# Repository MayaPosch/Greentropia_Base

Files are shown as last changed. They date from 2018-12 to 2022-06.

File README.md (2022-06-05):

# Greentropia Base Board #

The [Greentropia](http://www.nyantronics.com/greentropia.php "Greentropia") (formerly IoP) Base board is a fairly simple PCB aimed at monitoring and watering single plants or similar configurations. Its block diagram looks as follows:

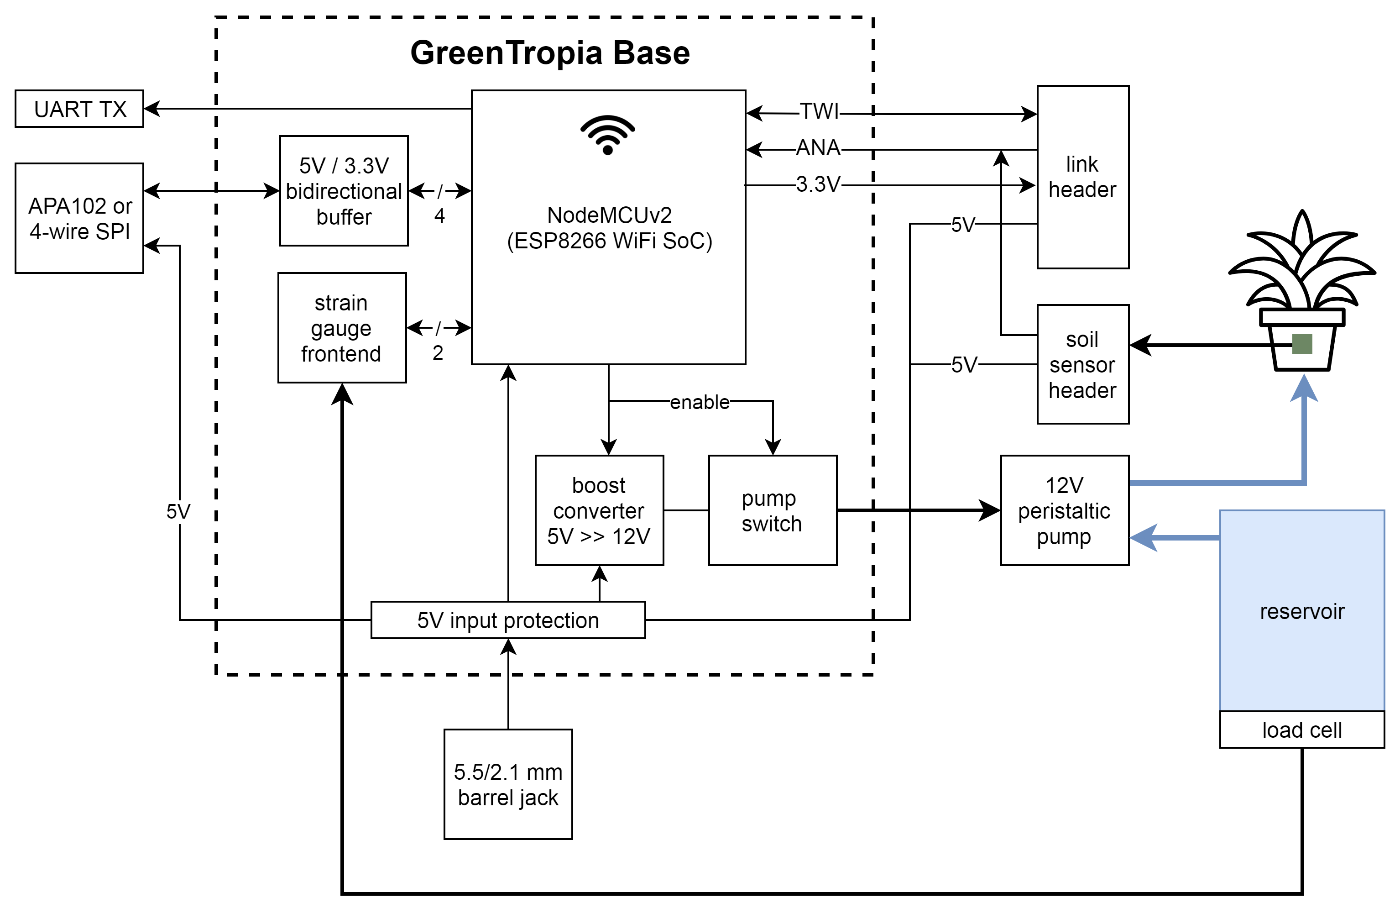
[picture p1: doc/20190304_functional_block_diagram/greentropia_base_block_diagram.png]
Base Diagram


This is the final board (without NodeMCU board installed):

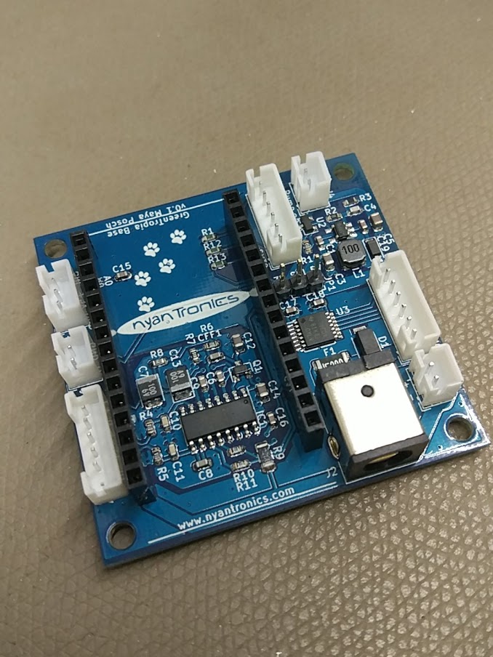
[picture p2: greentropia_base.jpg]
Base Board


This repository contains the full KiCad project for the board. More information about the Greentropia project can be found at [Nyantronics](http://nyantronics.com/ "Nyantronics.com").

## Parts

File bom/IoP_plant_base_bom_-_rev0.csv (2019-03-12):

Id | Designator | Package | Quantity | Designation | Supplier and ref
1 | U1 | DIP2286W64P254L4826H735Q30N | 1 | NodeMCUv2
2 | SPI0,EXT0 | JST_PH_B6B-PH-K_1x06_P2.00mm_Vertical | 2 | Conn_01x06
3 | J4,J1,J6 | JST_PH_B2B-PH-K_1x02_P2.00mm_Vertical | 3 | Conn_01x02
4 | U2 | SOT-23-5_HandSoldering | 1 | LM27313XMF
5 | U3 | TSSOP-14_4.4x5mm_P0.65mm | 1 | TXB0104PWR
6 | R14,R5,R4,R10,R11 | R_0603_1608Metric | 5 | 100
7 | R13,R12,R1 | R_0603_1608Metric | 3 | 4.7k
8 | Q2 | SOT-23 | 1 | IRLML6244
9 | JP1 | PinHeader_1x03_P2.54mm_Vertical | 1 | Jumper_3_Bridged12
10 | D3 | D_SOD-523 | 1 | ESD5Z12T1G
11 | C19,C18,C17,C1,C16,C6 | C_0603_1608Metric | 6 | 100nF
12 | C5 | C_0805_2012Metric | 1 | 4.7uF
14 | J2 | BarrelJack_CUI_PJ-063AH_Horizontal | 1 | Jack-DC
15 | J5 | JST_PH_B3B-PH-K_1x03_P2.00mm_Vertical | 1 | Conn_01x03
16 | J7 | JST_PH_B5B-PH-K_1x05_P2.00mm_Vertical | 1 | Conn_01x05
17 | D1 | D_SMA | 1 | 1N4004
18 | F1 | Fuse_1812_4532Metric | 1 | Polyfuse
19 | R9 | R_1206_3216Metric | 1 | 100R
20 | C3,C12,C14 | C_0805_2012Metric | 3 | 10uF
21 | C15,C9 | C_0603_1608Metric | 2 | 0.1uF
22 | C4 | C_0603_1608Metric | 1 | 220pF
23 | C8,CFF1 | C_0603_1608Metric | 2 | 1uF
24 | D2 | D_SOD-123 | 1 | MBR0520L
25 | R7 | R_0603_1608Metric | 1 | 1.0k
26 | R6 | R_0603_1608Metric | 1 | 2.0k
27 | R3 | R_0603_1608Metric | 1 | 117K
28 | R2 | R_0603_1608Metric | 1 | 13.3K
29 | L1 | L_Wuerth_MAPI-4020 | 1 | 10uH
30 | IC1 | SOIC-16_3.9x9.9mm_Pitch1.27mm | 1 | HX711
31 | R8 | R_0603_1608Metric | 1 | 10R
32 | Q1 | SOT-23 | 1 | BC857C
33 | C13,C7 | CP_EIA-3528-15_AVX-H | 2 | 100uF/6.3V
34 | C11,C10 | C_0603_1608Metric | 2 | 10nF

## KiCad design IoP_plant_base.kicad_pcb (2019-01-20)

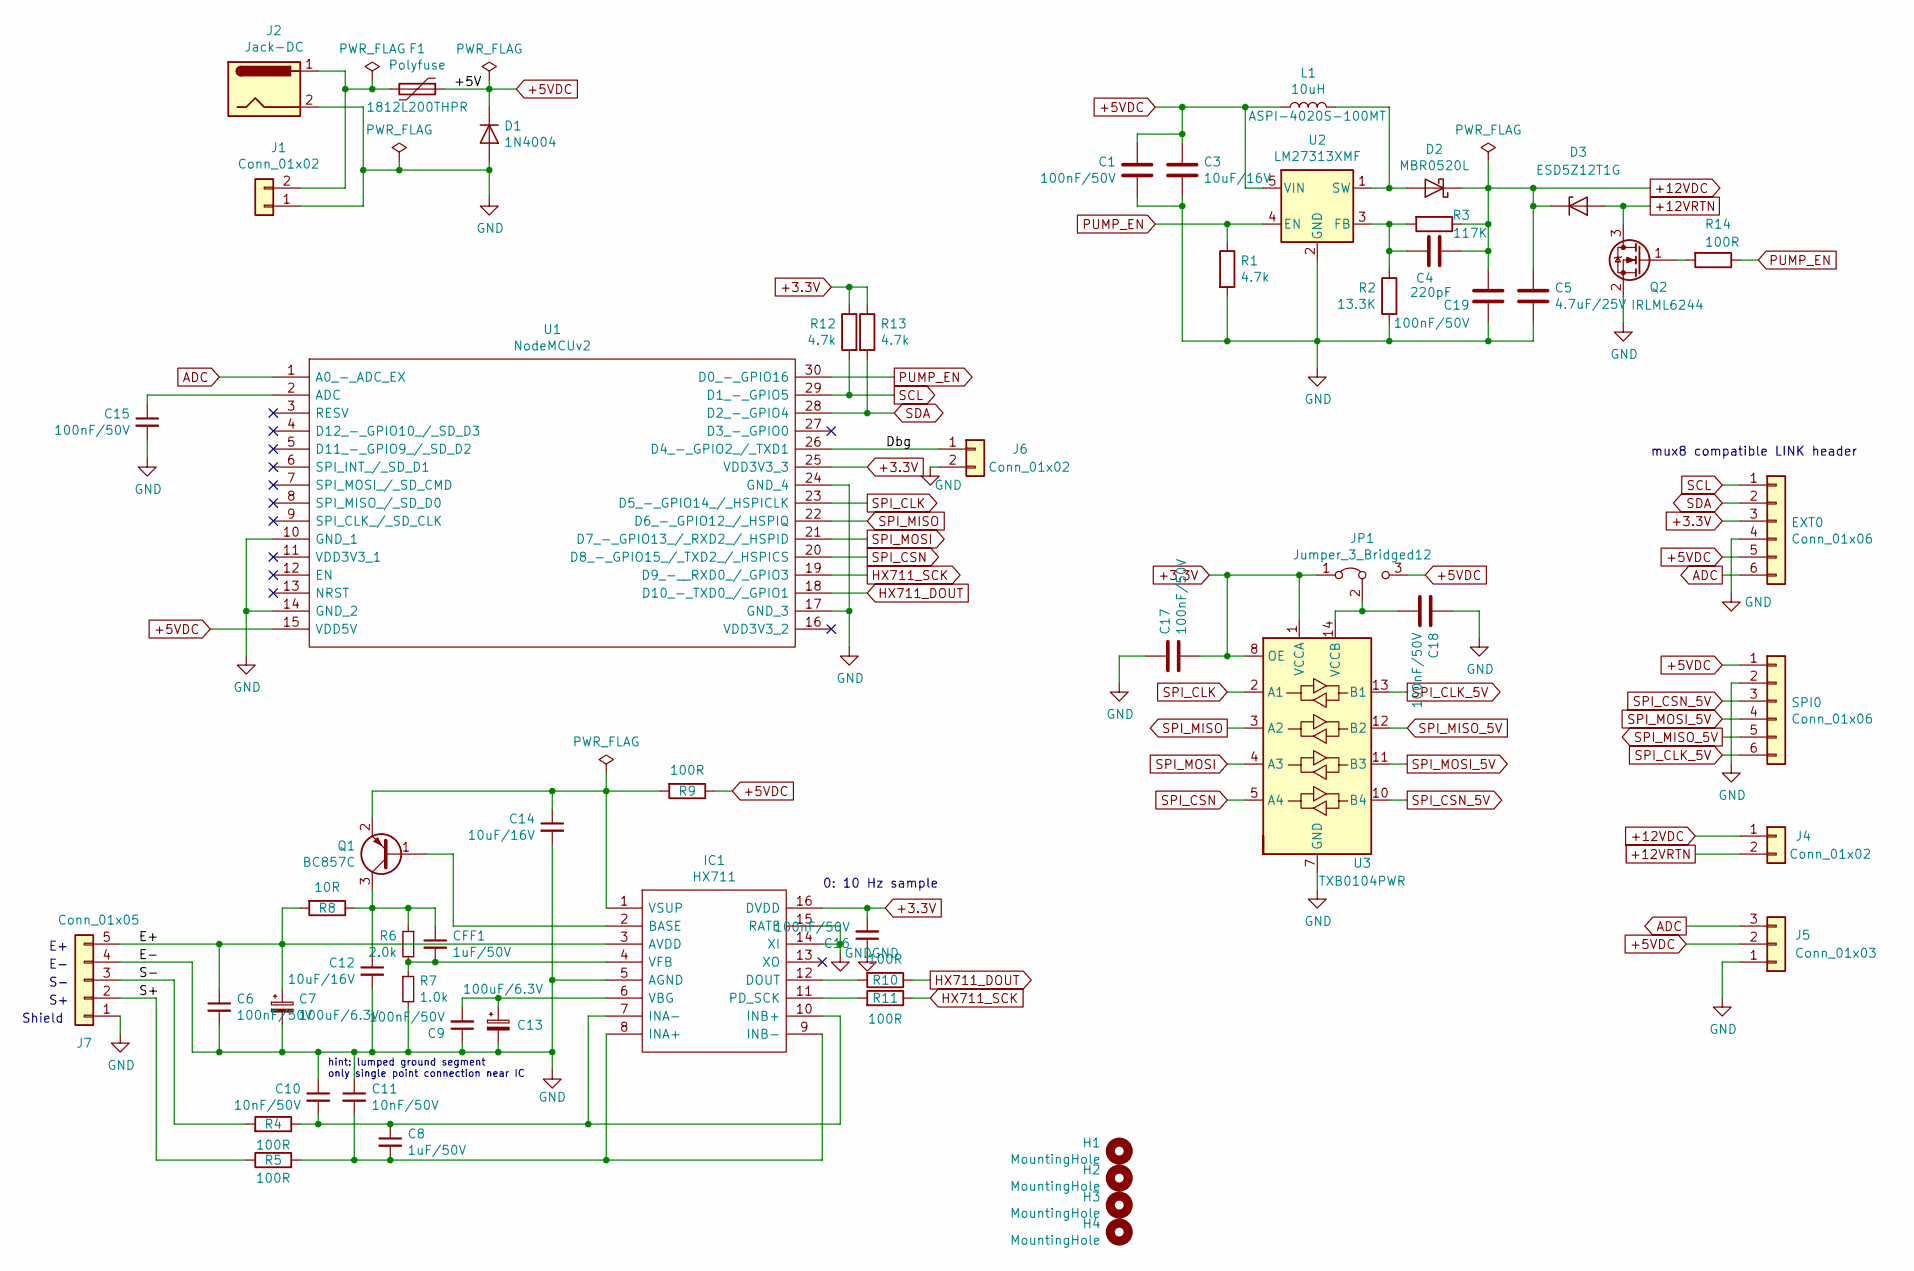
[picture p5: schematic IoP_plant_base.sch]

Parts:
C1, C6, C9, C15, C16, C17, C18, C19: 100nF/50V; C_0603_1608Metric; Mouser 603-CC603KRX7R9BB104
C3, C12, C14: 10uF/16V; C_0805_2012Metric; Mouser 80-C0805C475M9RAUTO
C4: 220pF; C_0603_1608Metric; Mouser 81-GCM1885C2A221J16D
C5: 4.7uF/25V; C_0805_2012Metric; Mouser 81-GCM21BC71E475KE6L
C7, C13: 100uF/6.3V; CP_EIA-3528-15_AVX-H; MPN F930J107KBA; Mouser 647-F930J107KBA
C8: 1uF/50V; C_0603_1608Metric; Mouser 963-LMK212B7225KG-T
C10, C11: 10nF/50V; C_0603_1608Metric; Mouser 710-885012206089
CFF1: 1uF/50V; C_0603_1608Metric; Mouser 963-LMK212B7225KG-T
D1: 1N4004; D_SMA; MPN MRA4004T3G; Mouser 863-MRA4004T3G
D2: MBR0520L; D_SOD-123; MPN MBR0520L; Mouser 512-MBR0520L
D3: ESD5Z12T1G; D_SOD-523; MPN ESD5Z12T1G; Mouser 863-ESD5Z12T1G
EXT0: Conn_01x06; JST_PH_B6B-PH-K_1x06_P2.00mm_Vertical; Digikey 455-1708-ND
F1: Polyfuse; Fuse_1812_4532Metric; MPN 1812L200THPR; Mouser 576-1812L200THPR
H1, H2, H3, H4: MountingHole; MountingHole_3.2mm_M3_DIN965
IC1: HX711; SOIC-16_3.9x9.9mm_Pitch1.27mm; Manufacturer_Part_Number HX711
J1, J4, J6: Conn_01x02; JST_PH_B2B-PH-K_1x02_P2.00mm_Vertical; Digikey 455-1704-ND
J2: Jack-DC; BarrelJack_CUI_PJ-063AH_Horizontal; MPN PJ-063AH; Mouser 490-PJ-063AH
J5: Conn_01x03; JST_PH_B3B-PH-K_1x03_P2.00mm_Vertical; Digikey 455-1705-ND
J7: Conn_01x05; JST_PH_B5B-PH-K_1x05_P2.00mm_Vertical; Digikey 455-1707-ND
JP1: Jumper_3_Bridged12; PinHeader_1x03_P2.54mm_Vertical
L1: 10uH; L_Wuerth_MAPI-4020; MPN2 74438357100; Mouser2 710-74438357100
Q1: BC857C; SOT-23; MPN BC857CWT1G; Mouser 863-BC857CWT1G
Q2: IRLML6244; SOT-23; MPN IRLML6244TRPBF; Mouser 942-IRLML6244TRPBF
R1, R12, R13: 4.7k; R_0603_1608Metric
R2: 13.3K; R_0603_1608Metric; Mouser 71-CRCW0603-13.3K-E3
R3: 117K; R_0603_1608Metric; Mouser 603-RT0603DRE07117KL
R4, R5, R10, R11, R14: 100R; R_0603_1608Metric
R6: 2.0k; R_0603_1608Metric; Mouser 71-CRCW0603-2.0K-E3
R7: 1.0k; R_0603_1608Metric
R8: 10R; R_0603_1608Metric
R9: 100R; R_1206_3216Metric
SPI0: Conn_01x06; JST_PH_B6B-PH-K_1x06_P2.00mm_Vertical; Digikey 455-1708-ND
U1: NodeMCUv2; DIP2286W64P254L4826H735Q30N; Mouser Part Number 713-113990105
U2: LM27313XMF; SOT-23-5_HandSoldering; MPN LM27313XMF/NOPB; Mouser 926-LM27313XMF/NOPB
U3: TXB0104PWR; TSSOP-14_4.4x5mm_P0.65mm; MPN TXB0104PWR; Mouser 595-TXB0104PWR

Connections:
+3.3V: C16.2, C17.2, EXT0.3, IC1.16 (DVDD), JP1.1 (A), R12.1, R13.1, U1.25 (VDD3V3_3), U3.1 (VCCA), U3.8 (OE)
+5VDC: C1.1, C3.1, D1.1 (K), EXT0.5, F1.1, J5.2, JP1.3 (B), L1.1, R9.1, SPI0.1, U1.15 (VDD5V), U2.5 (VIN)
+12VDC: C4.2, C5.1, C19.1, D2.1 (K), D3.1 (K), J4.1, R3.1
+12VRTN: D3.2 (A), J4.2, Q2.3 (D)
/Dbg: J6.1, U1.26 (D4_-_GPIO2_/_TXD1)
/E+: C6.1, C7.1, IC1.3 (AVDD), J7.5, R8.2
/S+: J7.2, R5.1
/S-: J7.3, R4.2
ADC: EXT0.6, J5.3, U1.1 (A0_-_ADC_EX)
GND: C1.2, C3.2, C5.2, C6.2, C7.2, C9.1, C10.1, C11.1, C12.2, C13.2, C14.2, C15.2, C16.1, C17.1, C18.1, C19.2, D1.2 (A), EXT0.4, IC1.5 (AGND), IC1.14 (XI), IC1.15 (RATE), J1.1, J2.2, J5.1, J6.2, J7.1, J7.4, Q2.2 (S), R1.2, R2.2, R7.2, SPI0.2, U1.10 (GND_1), U1.14 (GND_2), U1.17 (GND_3), U1.24 (GND_4), U2.2 (GND), U3.7 (GND)
HX711_DOUT: R10.1, U1.18 (D10_-_TXD0_/_GPIO1)
HX711_SCK: R11.1, U1.19 (D9_-__RXD0_/_GPIO3)
unnamed: C4.1, R2.1, R3.2, U2.3 (FB)
unnamed: C8.1, C10.2, IC1.7 (INA-), IC1.10 (INB+), R4.1
unnamed: C8.2, C11.2, IC1.8 (INA+), IC1.9 (INB-), R5.2
unnamed: C12.1, CFF1.1, Q1.3 (C), R6.1, R8.1
unnamed: C9.2, C13.1, IC1.6 (VBG)
unnamed: C14.1, IC1.1 (VSUP), Q1.2 (E), R9.2
unnamed: C15.1, U1.2 (ADC)
unnamed: C18.2, JP1.2 (C), U3.14 (VCCB)
unnamed: CFF1.2, IC1.4 (VFB), R6.2, R7.1
unnamed: D2.2 (A), L1.2, U2.1 (SW)
unnamed: F1.2, J1.2, J2.1
unnamed: IC1.2 (BASE), Q1.1 (B)
unnamed: IC1.11 (PD_SCK), R11.2
unnamed: IC1.12 (DOUT), R10.2
unnamed: Q2.1 (G), R14.2
PUMP_EN: R1.1, R14.1, U1.30 (D0_-_GPIO16), U2.4 (EN)
SCL: EXT0.1, R12.2, U1.29 (D1_-_GPIO5)
SDA: EXT0.2, R13.2, U1.28 (D2_-_GPIO4)
SPI_CLK: U1.23 (D5_-_GPIO14_/_HSPICLK), U3.2 (A1)
SPI_CLK_5V: SPI0.6, U3.13 (B1)
SPI_CSN: U1.20 (D8_-_GPIO15_/_TXD2_/_HSPICS), U3.5 (A4)
SPI_CSN_5V: SPI0.3, U3.10 (B4)
SPI_MISO: U1.22 (D6_-_GPIO12_/_HSPIQ), U3.3 (A2)
SPI_MISO_5V: SPI0.5, U3.12 (B2)
SPI_MOSI: U1.21 (D7_-_GPIO13_/_RXD2_/_HSPID), U3.4 (A3)
SPI_MOSI_5V: SPI0.4, U3.11 (B3)

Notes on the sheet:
Shield
0: 10 Hz sample
hint: lumped ground segment only single point connection near IC
mux8 compatible LINK header

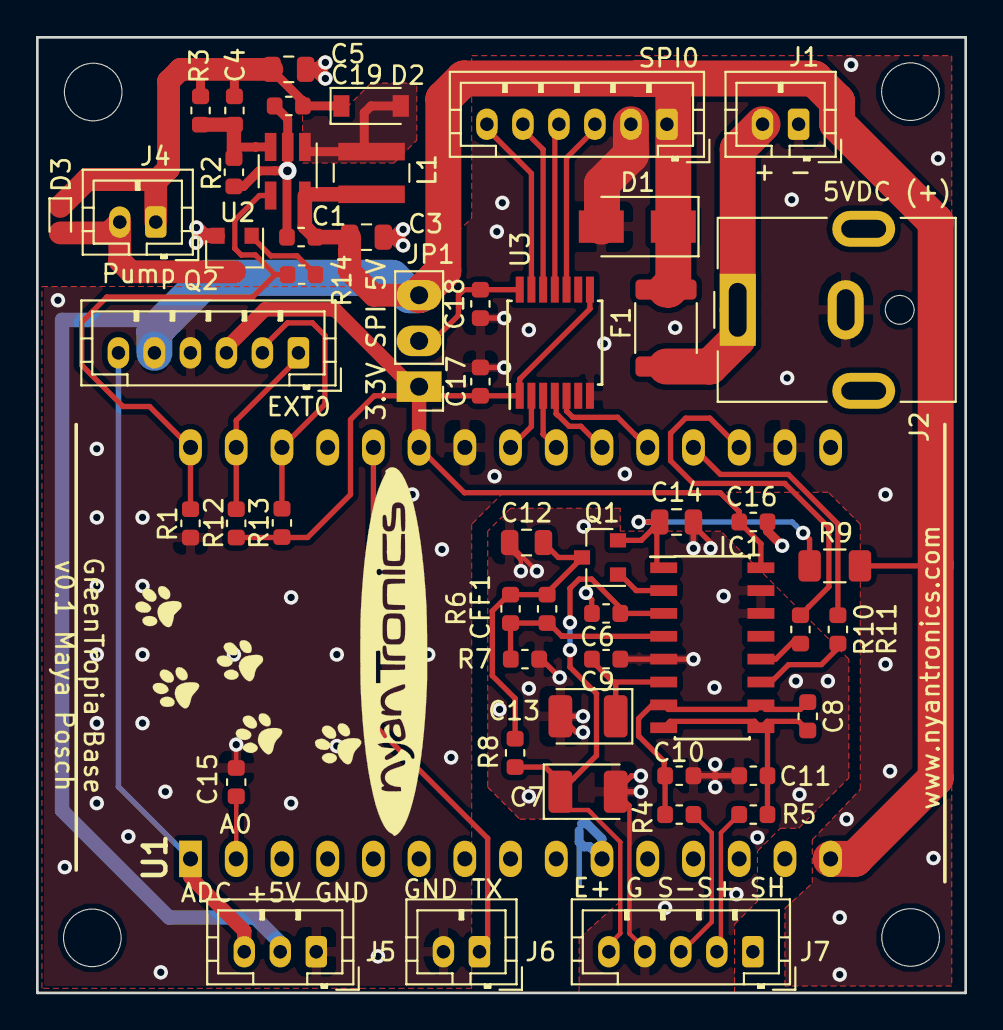
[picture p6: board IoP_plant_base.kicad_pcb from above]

Board: 2 copper layers, 51.6 x 53.1 mm, 57 parts (0 on the bottom side), 38 nets.

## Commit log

2018-09-07 Initial commit. Added SPI breakout with level converter.
    [IoP_plant_base.kicad_pcb, IoP_plant_base.sch]
2018-09-12 Started routing boost converter. TODO: footprint name fixing.
    [IoP_plant_base.kicad_pcb, IoP_plant_base.sch]
2018-12-22 Finish initial PCB routing.
    [IoP_plant_base.kicad_pcb, IoP_plant_base.sch]
2018-12-26 * renamed SPI_INT to SPI_CSN * remapped SPI pins to HSPI (no overlap with internal flash) * renamed time critical / permanently driven HX711 pseudo-SPI pins to GPIO1 / GPIO3 such that RXD0 can overri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
    [IoP_plant_base.sch]
2018-12-26 PCB schematic and layout updated. More changes to actual footprints (all headers are now vertical), some BOM info added. Re-routed DCDC section. *** TODO *** rules-check everything including pinouts.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
    [IoP_plant_base.kicad_pcb, IoP_plant_base.sch]
2018-12-27 Generate Gerber files. Small silkscreen tweaks & clean-up.
    [IoP_plant_base-B.Cu.gbr, IoP_plant_base-B.Mask.gbr, IoP_plant_base-B.Paste.gbr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]
2018-12-27 Add ZIP file with Gerbers.
2019-01-03 fixed inconsistent parts values, preliminary BOM created (missing Mouser part numbers)
    [IoP_plant_base.kicad_pcb, IoP_plant_base.sch, IoP_plant_base_bom_-_rev0.csv]
2019-01-20 updated BOM info according to Mouser order. Note: consider migrating to ME2149F SO8 for next rev. (higher current, ~30ct vs. 1.15€)
    [IoP_plant_base.kicad_pcb, IoP_plant_base.sch]
2019-03-12 Add README.
    [IoP_plant_base_bom_-_rev0.csv]
